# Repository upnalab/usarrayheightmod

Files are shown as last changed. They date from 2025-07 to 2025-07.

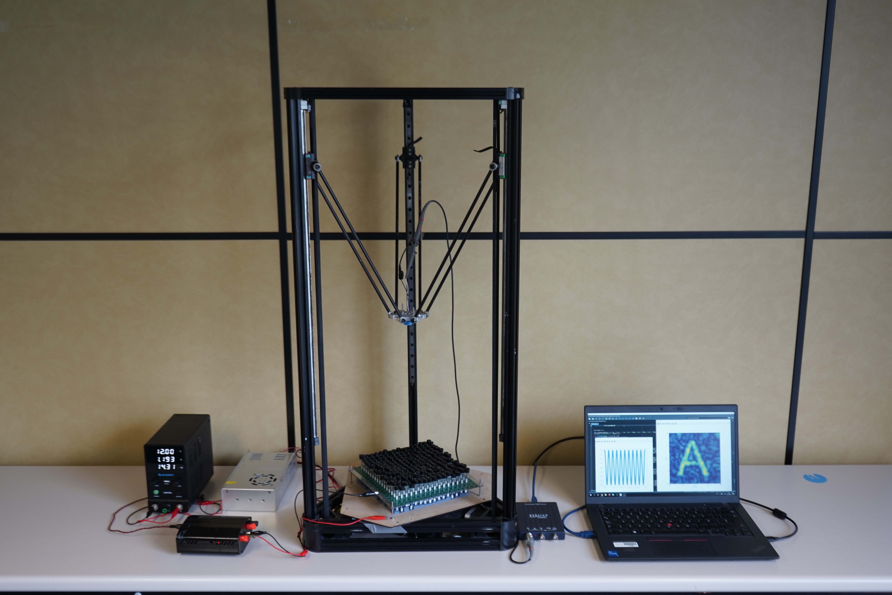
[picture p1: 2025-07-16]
Paper Photos/All Photos/Scan_SetUp/_DSC2688.JPG

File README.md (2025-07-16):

# Generating High-amplitude Acoustic Patterns by Reconfiguring the Height of Emitters Arrays
**Authors:** Mikel Aldea<sup>1</sup>, Soma Mochizuki<sup>2</sup>, Manuel Lopez-Amo<sup>1</sup>, Ivan Fernandez<sup>1</sup>, Tatsuki Fushimi<sup>3</sup> and Asier Marzo<sup>1</sup>.

**Affiliation 1)** Universidad Pública de Navarra, Departamento de Estadística, Informática y Matemáticas, Pamplona, Spain. 

**Affiliation 2)** Graduate School of Comprehensive Human Sciences, University of Tsukuba, Tsukuba, 305-8550 Ibaraki, Japan. 

**Affiliation 3)** Institute of Library, Information and Media Science, University of Tsukuba, Kasuga Campus Kasuga 1-2, Tsukuba 305-8550, Ibaraki, Japan.

Paper published in:

DOI:

Detailed explanation of the files in the git:
```
├── ArrayAmpSliceHeight.py                           -> Main function of the code. Contains a python class to optimize the heights of a grid of transducers while keeping the phase to 0 for all the emitters in the grid. This heights are trained to generate an acoustic pattern at a desired height.
├── Waves.py                                         -> Contains helper functions used throughout the main code. These functions encapsulate common operations such as gneerate a planeGrid, generate normals for the phased array, compute the propagators to calculate the simulated acoustic fields.
├── ImageUtils.py                                    -> Contains functions used to load the images of the desired target pattern to optimize.
├── TestArrayAmpSliceHeight.py                       -> Main executable for ArrayAmpSliceHeight.py. It computes the idea heights for the 3 patterns presented in the paper.
├── TestArrayAmpSliceHeight_ForMNIST10.py            -> Similar to TestArrayAmpSliceHeight.py but used for Figure 4 and 5 of the paper. This code compares the proposed method in the paper against existance method such as Phased optimization. The patterns used to compare are extracted from MNIST10 dataset. 
├── PatternMeasurements.py                           -> Code used to take experimental measurements. It is designed to serally connect to a delta printer (BIQU Kossel9 Plus) and to a PicoScope2004A Series (attached to the tip of the printer). The extruder will be moved in a sqaure grid to take measuremnt of the acoustic field in each step.
├── UtilsMeasurement.py                              -> Contains helper function to both connect to the printer and to the PicoScope.
├── VisualizeMeasurement.py                          -> Code that can be executed to visually check the measurement taken.
├── CreatePlateFromEmitters.py                       -> Generates a mesh to transform into an STL with the heights of the transducers computed by the algorithm proposed in this paper.
├── results                                          -> Result obtained in the paper. ** stands for the specific pattern depicted in each image (i.e., a star shape, the letter A, or the number 12).                         
    ├── Experiment_VS_Simulation_HeightMod_**.png    
    ├── sim_**.png                                   
    ├── meshes                                       -> Mesh generated by CreatePlateFromEmitters.py. This files can be used to generate the metasurfaces used in the paper.
        └── Mesh_heightMod_**.scad                   
    └── STLs                                         -> STLs for the 3D printing the metasurfaces.
        └── STL_heightMod_**.stl
├── measurements                                    -> Directory used to store all the experimental data produced by the paper.
    ├── GenerateImageExpAndSim.py                   -> Code used to generate the images to produce Figure 3 in the article.
    ├── target_**.png
    ├── sim_**.png
    ├── experHeightMod_**.png
    ├── ExperimentalData_HeightMod                  -> Experimental data recorded by the PicoScope each csv in a 128x128 grid of values obtained from the experiments.
        └── HeightMod_**.csv
    └── Simulations                                 -> Simulations used to compare against the experimental data. Each csv has 256 rows where each row provides information about the transducer in the phased array. the file format is: x,y,z,nx,ny,nz,power,frequency,apperture,Type(0=circle,1=square),sx,sy,sz,phase.
        ├── heightMod_**.csv
        └── VisualizeDataFromCsv.py
├── patterns                                        -> This directory contains the images of the patterns used in the paper. This patterns included a star shape, the letter A, the number 12 and 10 random images from MNIST 10 dataset.
│   ├── 12.png
│   ├── A.png
│   ├── star.png
│   ├── mnist10
│   │   ├── Label_0.jpeg
│   │   └── ...
└── results_MNIST10                                -> Stored the results for evaluating and comparing the different optimization methods against the model discussed in the paper.
    └── ...
└── paper photos                                   -> Includes photos taken for the paper and the figures used in the latter.
    └── ...
```

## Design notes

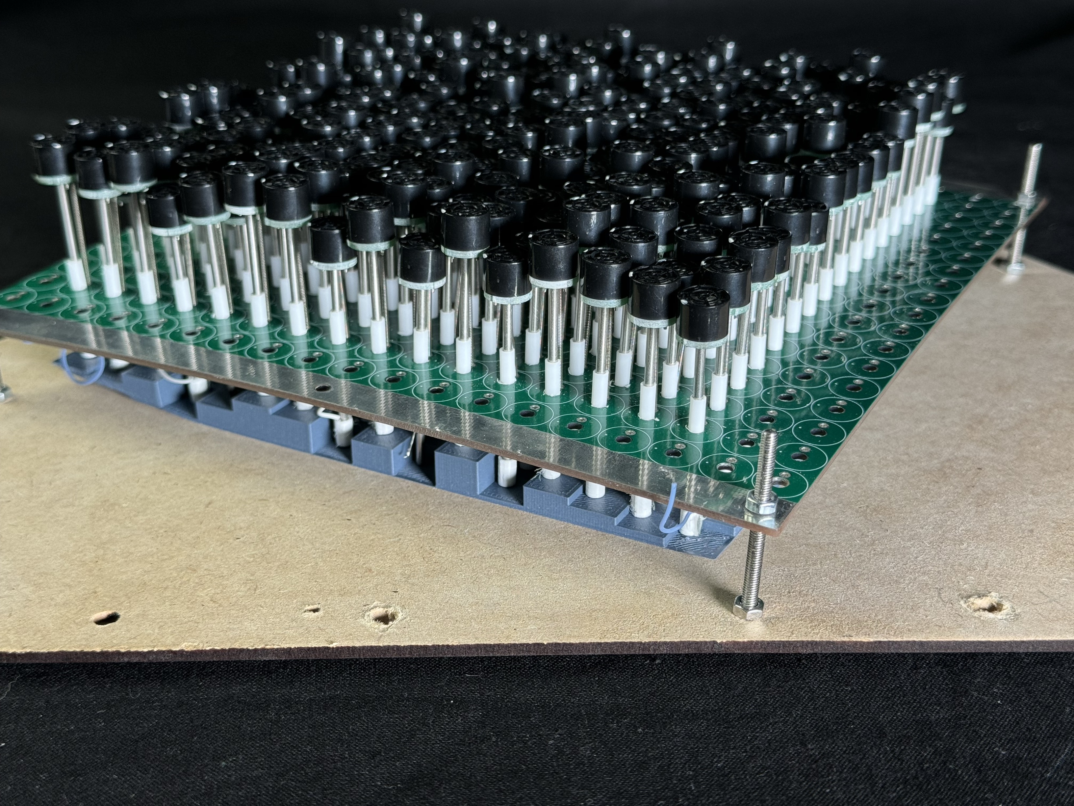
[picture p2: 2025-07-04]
Paper Photos/All Photos/Array/Foto59.png

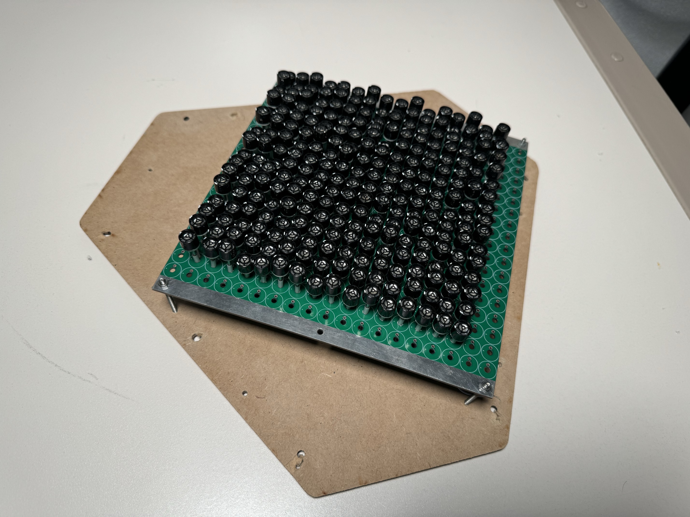
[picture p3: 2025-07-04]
Paper Photos/All Photos/Array/Foto21.png

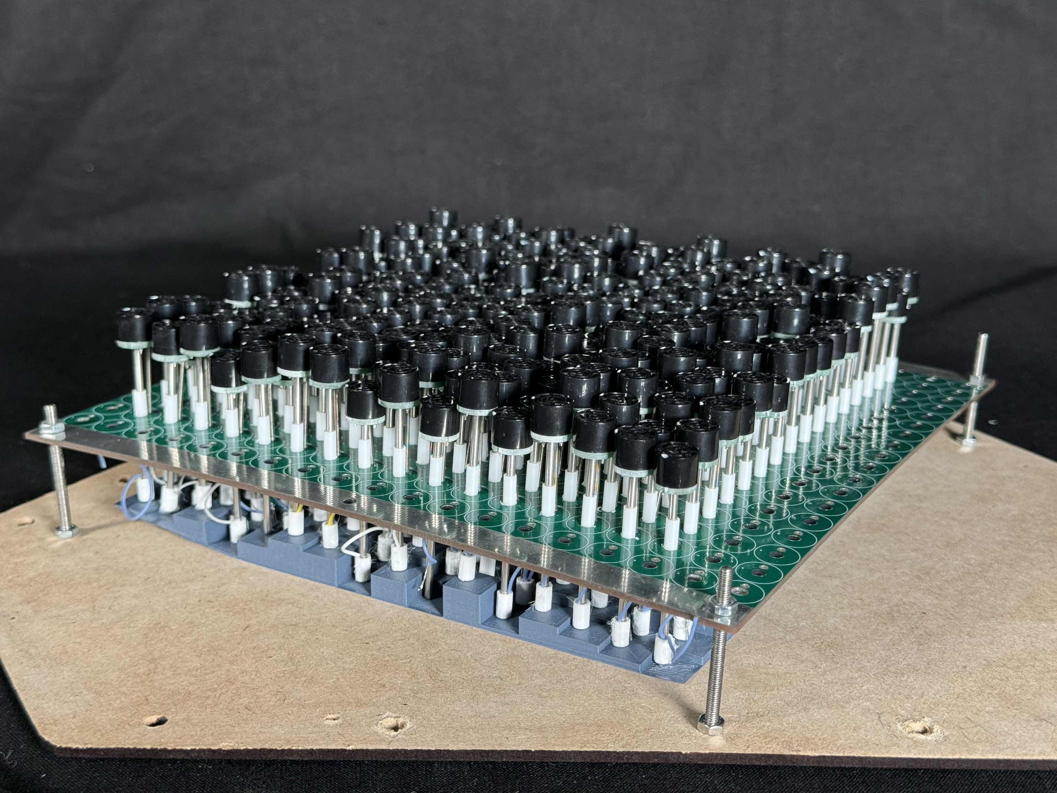
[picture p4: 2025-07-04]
Paper Photos/All Photos/Array/Foto34.png

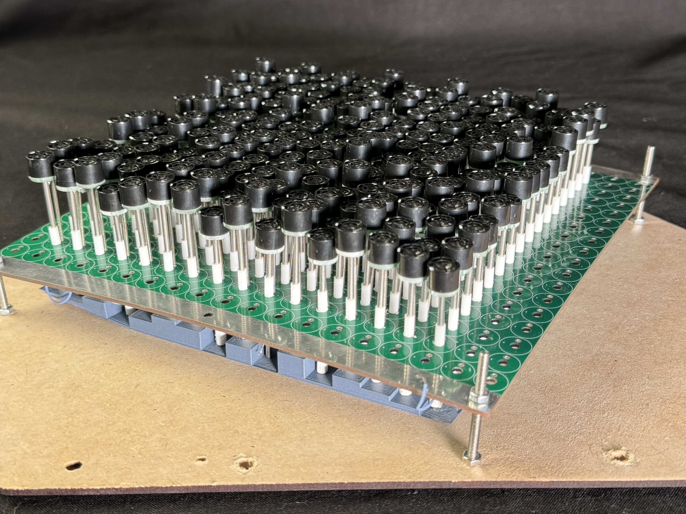
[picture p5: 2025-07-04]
Paper Photos/All Photos/Array/Foto56.png

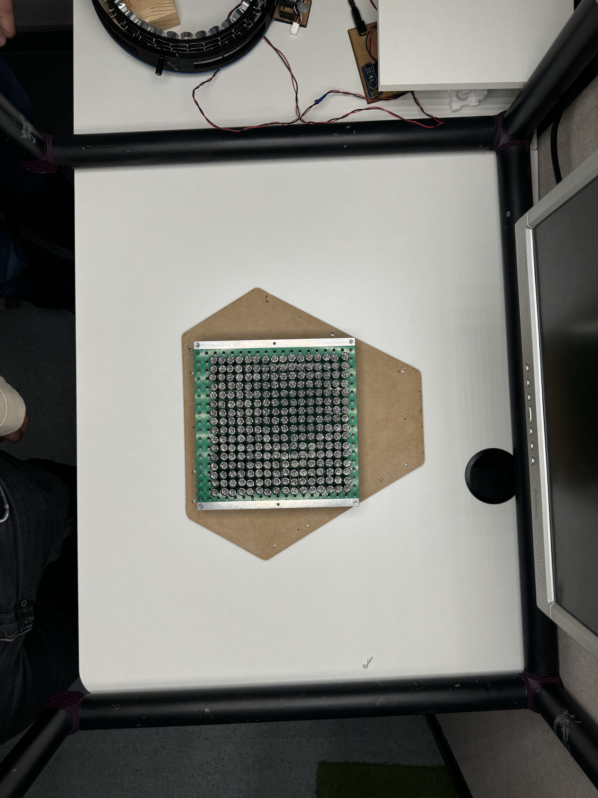
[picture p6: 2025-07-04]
Paper Photos/All Photos/Array/Foto14.png

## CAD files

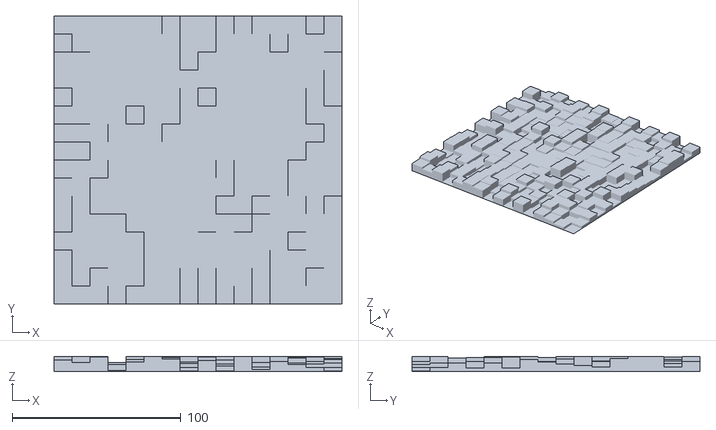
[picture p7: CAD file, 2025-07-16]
results/STLs/STL_heightMod_A.stl
170.7 x 170.7 x 8.70

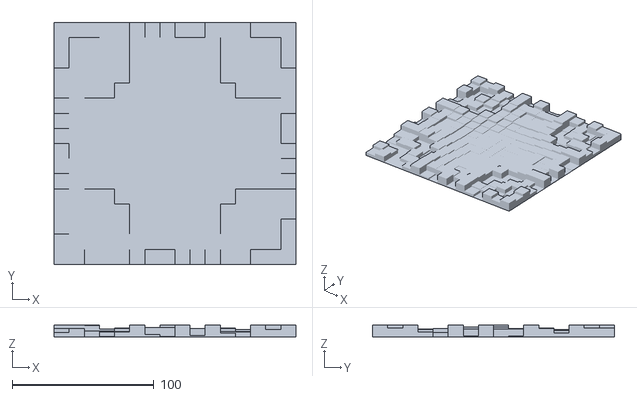
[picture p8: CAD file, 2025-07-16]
results/STLs/STL_heightMod_Star.stl
170.7 x 170.7 x 8.70

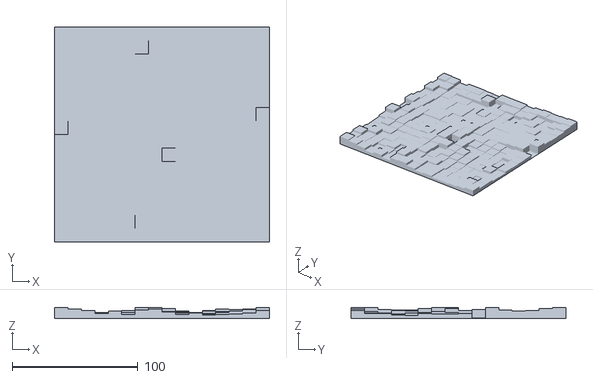
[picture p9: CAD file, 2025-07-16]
results/STLs/STL_heightMod_12.stl
170.7 x 170.7 x 8.70

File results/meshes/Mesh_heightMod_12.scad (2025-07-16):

union() {
	translate(v = [-85.33333333333334, -85.33333333333334, 0]) {
		cube(size = [10.6666666666667, 10.6666666666667, 8.700000461935899]);
	}
	translate(v = [-74.66666666666666, -85.33333333333334, 0]) {
		cube(size = [10.6666666666667, 10.6666666666667, 7.5061604052782]);
	}
	translate(v = [-63.99999999999995, -85.33333333333334, 0]) {
		cube(size = [10.6666666666667, 10.6666666666667, 6.1725968167185]);
	}
	translate(v = [-53.33333333333335, -85.33333333333334, 0]) {
		cube(size = [10.6666666666667, 10.6666666666667, 3.813871987909]);
	}
	translate(v = [-42.66666666666665, -85.33333333333334, 0]) {
		cube(size = [10.6666666666667, 10.6666666666667, 5.8566777639091]);
	}
	translate(v = [-31.99999999999995, -85.33333333333334, 0]) {
		cube(size = [10.6666666666667, 10.6666666666667, 3.2827173031866]);
	}
	translate(v = [-21.33333333333335, -85.33333333333334, 0]) {
		cube(size = [10.6666666666667, 10.6666666666667, 6.8355797462165]);
	}
	translate(v = [-10.66666666666665, -85.33333333333334, 0]) {
		cube(size = [10.6666666666667, 10.6666666666667, 7.645706985890801]);
	}
	translate(v = [-4.973799150320701e-14, -85.33333333333334, 0]) {
		cube(size = [10.6666666666667, 10.6666666666667, 5.1123354256153]);
	}
	translate(v = [10.66666666666665, -85.33333333333334, 0]) {
		cube(size = [10.6666666666667, 10.6666666666667, 3.2912335496394998]);
	}
	translate(v = [21.33333333333325, -85.33333333333334, 0]) {
		cube(size = [10.6666666666667, 10.6666666666667, 4.2894309058785]);
	}
	translate(v = [31.99999999999995, -85.33333333333334, 0]) {
		cube(size = [10.6666666666667, 10.6666666666667, 2.8622421573847]);
	}
	translate(v = [42.66666666666665, -85.33333333333334, 0]) {
		cube(size = [10.6666666666667, 10.6666666666667, 2.9689922135323004]);
	}
	translate(v = [53.33333333333325, -85.33333333333334, 0]) {
		cube(size = [10.6666666666667, 10.6666666666667, 3.4237507402896004]);
	}
	translate(v = [63.99999999999995, -85.33333333333334, 0]) {
		cube(size = [10.6666666666667, 10.6666666666667, 4.533003424108]);
	}
	translate(v = [74.66666666666666, -85.33333333333334, 0]) {
		cube(size = [10.6666666666667, 10.6666666666667, 6.1867124073207]);
	}
	translate(v = [-85.33333333333334, -74.66666666666666, 0]) {
		cube(size = [10.6666666666667, 10.6666666666667, 5.3155630499124]);
	}
	translate(v = [-74.66666666666666, -74.66666666666666, 0]) {
		cube(size = [10.6666666666667, 10.6666666666667, 4.467711192369401]);
	}
	translate(v = [-63.99999999999995, -74.66666666666666, 0]) {
		cube(size = [10.6666666666667, 10.6666666666667, 4.082786724716399]);
	}
	translate(v = [-53.33333333333335, -74.66666666666666, 0]) {
		cube(size = [10.6666666666667, 10.6666666666667, 1.6185141772030998]);
	}
	translate(v = [-42.66666666666665, -74.66666666666666, 0]) {
		cube(size = [10.6666666666667, 10.6666666666667, 3.0523833025246003]);
	}
	translate(v = [-31.99999999999995, -74.66666666666666, 0]) {
		cube(size = [10.6666666666667, 10.6666666666667, 1.8066216630861]);
	}
	translate(v = [-21.33333333333335, -74.66666666666666, 0]) {
		cube(size = [10.6666666666667, 10.6666666666667, 8.700000461935899]);
	}
	translate(v = [-10.66666666666665, -74.66666666666666, 0]) {
		cube(size = [10.6666666666667, 10.6666666666667, 5.2259600393474]);
	}
	translate(v = [-4.973799150320701e-14, -74.66666666666666, 0]) {
		cube(size = [10.6666666666667, 10.6666666666667, 5.390020892769001]);
	}
	translate(v = [10.66666666666665, -74.66666666666666, 0]) {
		cube(size = [10.6666666666667, 10.6666666666667, 3.0766558971256]);
	}
	translate(v = [21.33333333333325, -74.66666666666666, 0]) {
		cube(size = [10.6666666666667, 10.6666666666667, 4.027566280961]);
	}
	translate(v = [31.99999999999995, -74.66666666666666, 0]) {
		cube(size = [10.6666666666667, 10.6666666666667, 2.3891125943511002]);
	}
	translate(v = [42.66666666666665, -74.66666666666666, 0]) {
		cube(size = [10.6666666666667, 10.6666666666667, 1.9034379998221]);
	}
	translate(v = [53.33333333333325, -74.66666666666666, 0]) {
		cube(size = [10.6666666666667, 10.6666666666667, 1.8246892046183]);
	}
	translate(v = [63.99999999999995, -74.66666666666666, 0]) {
		cube(size = [10.6666666666667, 10.6666666666667, 4.4788172140717]);
	}
	translate(v = [74.66666666666666, -74.66666666666666, 0]) {
		cube(size = [10.6666666666667, 10.6666666666667, 3.8776547785848003]);
	}
	translate(v = [-85.33333333333334, -63.99999999999995, 0]) {
		cube(size = [10.6666666666667, 10.6666666666667, 6.897682198137]);
	}
	translate(v = [-74.66666666666666, -63.99999999999995, 0]) {
		cube(size = [10.6666666666667, 10.6666666666667, 3.8400603130459]);
	}
	translate(v = [-63.99999999999995, -63.99999999999995, 0]) {
		cube(size = [10.6666666666667, 10.6666666666667, 3.4093536574393]);
	}
	translate(v = [-53.33333333333335, -63.99999999999995, 0]) {
		cube(size = [10.6666666666667, 10.6666666666667, 2.8971441693603]);
	}
	translate(v = [-42.66666666666665, -63.99999999999995, 0]) {
		cube(size = [10.6666666666667, 10.6666666666667, 4.6724410399794]);
	}
	translate(v = [-31.99999999999995, -63.99999999999995, 0]) {
		cube(size = [10.6666666666667, 10.6666666666667, 2.4921981289982003]);
	}
	translate(v = [-21.33333333333335, -63.99999999999995, 0]) {
		cube(size = [10.6666666666667, 10.6666666666667, 7.2442627184093]);
	}
	translate(v = [-10.66666666666665, -63.99999999999995, 0]) {
		cube(size = [10.6666666666667, 10.6666666666667, 4.4911549098789]);
	}
	translate(v = [-4.973799150320701e-14, -63.99999999999995, 0]) {
		cube(size = [10.6666666666667, 10.6666666666667, 2.8251855306327003]);
	}
	translate(v = [10.66666666666665, -63.99999999999995, 0]) {
		cube(size = [10.6666666666667, 10.6666666666667, 4.5256282806396]);
	}
	translate(v = [21.33333333333325, -63.99999999999995, 0]) {
		cube(size = [10.6666666666667, 10.6666666666667, 2.0661735812202]);
	}
	translate(v = [31.99999999999995, -63.99999999999995, 0]) {
		cube(size = [10.6666666666667, 10.6666666666667, 0.7307201645337]);
	}
	translate(v = [42.66666666666665, -63.99999999999995, 0]) {
		cube(size = [10.6666666666667, 10.6666666666667, 0.5089016827289]);
	}
	translate(v = [53.33333333333325, -63.99999999999995, 0]) {
		cube(size = [10.6666666666667, 10.6666666666667, 1.2173014597967]);
	}
	translate(v = [63.99999999999995, -63.99999999999995, 0]) {
		cube(size = [10.6666666666667, 10.6666666666667, 0.6361953178886]);
	}
	translate(v = [74.66666666666666, -63.99999999999995, 0]) {
		cube(size = [10.6666666666667, 10.6666666666667, 4.0184390868991]);
	}
	translate(v = [-85.33333333333334, -53.33333333333335, 0]) {
		cube(size = [10.6666666666667, 10.6666666666667, 3.388042435795]);
	}
	translate(v = [-74.66666666666666, -53.33333333333335, 0]) {
		cube(size = [10.6666666666667, 10.6666666666667, 6.1399888850748]);
	}
	translate(v = [-63.99999999999995, -53.33333333333335, 0]) {
		cube(size = [10.6666666666667, 10.6666666666667, 2.6903439916670004]);
	}
	translate(v = [-53.33333333333335, -53.33333333333335, 0]) {
		cube(size = [10.6666666666667, 10.6666666666667, 3.6316447563469]);
	}
	translate(v = [-42.66666666666665, -53.33333333333335, 0]) {
		cube(size = [10.6666666666667, 10.6666666666667, 3.4382959034293004]);
	}
	translate(v = [-31.99999999999995, -53.33333333333335, 0]) {
		cube(size = [10.6666666666667, 10.6666666666667, 4.7138685964047]);
	}
	translate(v = [-21.33333333333335, -53.33333333333335, 0]) {
		cube(size = [10.6666666666667, 10.6666666666667, 6.5388622365891]);
	}
	translate(v = [-10.66666666666665, -53.33333333333335, 0]) {
		cube(size = [10.6666666666667, 10.6666666666667, 6.215482824295701]);
	}
	translate(v = [-4.973799150320701e-14, -53.33333333333335, 0]) {
		cube(size = [10.6666666666667, 10.6666666666667, 3.5347285352647004]);
	}
	translate(v = [10.66666666666665, -53.33333333333335, 0]) {
		cube(size = [10.6666666666667, 10.6666666666667, 2.9948897331953]);
	}
	translate(v = [21.33333333333325, -53.33333333333335, 0]) {
		cube(size = [10.6666666666667, 10.6666666666667, 2.1912782590836]);
	}
	translate(v = [31.99999999999995, -53.33333333333335, 0]) {
		cube(size = [10.6666666666667, 10.6666666666667, 1.0774873567745]);
	}
	translate(v = [42.66666666666665, -53.33333333333335, 0]) {
		cube(size = [10.6666666666667, 10.6666666666667, 0.5528551605995]);
	}
	translate(v = [53.33333333333325, -53.33333333333335, 0]) {
		cube(size = [10.6666666666667, 10.6666666666667, 0.3810343528632]);
	}
	translate(v = [63.99999999999995, -53.33333333333335, 0]) {
		cube(size = [10.6666666666667, 10.6666666666667, 1.7551378019154]);
	}
	translate(v = [74.66666666666666, -53.33333333333335, 0]) {
		cube(size = [10.6666666666667, 10.6666666666667, 2.7600516237318002]);
	}
	translate(v = [-85.33333333333334, -42.66666666666665, 0]) {
		cube(size = [10.6666666666667, 10.6666666666667, 2.3933710668236]);
	}
	translate(v = [-74.66666666666666, -42.66666666666665, 0]) {
		cube(size = [10.6666666666667, 10.6666666666667, 3.8259142216295]);
	}
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

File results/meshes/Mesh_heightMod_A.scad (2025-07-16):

union() {
	translate(v = [-85.33333333333334, -85.33333333333334, 0]) {
		cube(size = [10.6666666666667, 10.6666666666667, 6.8611734218895]);
	}
	translate(v = [-74.66666666666666, -85.33333333333334, 0]) {
		cube(size = [10.6666666666667, 10.6666666666667, 5.3775104366242]);
	}
	translate(v = [-63.99999999999995, -85.33333333333334, 0]) {
		cube(size = [10.6666666666667, 10.6666666666667, 8.5248196169734]);
	}
	translate(v = [-53.33333333333335, -85.33333333333334, 0]) {
		cube(size = [10.6666666666667, 10.6666666666667, 0.5869419451802]);
	}
	translate(v = [-42.66666666666665, -85.33333333333334, 0]) {
		cube(size = [10.6666666666667, 10.6666666666667, 5.6032769985497]);
	}
	translate(v = [-31.99999999999995, -85.33333333333334, 0]) {
		cube(size = [10.6666666666667, 10.6666666666667, 8.700000461935899]);
	}
	translate(v = [-21.33333333333335, -85.33333333333334, 0]) {
		cube(size = [10.6666666666667, 10.6666666666667, 7.335332096368]);
	}
	translate(v = [-10.66666666666665, -85.33333333333334, 0]) {
		cube(size = [10.6666666666667, 10.6666666666667, 0.2]);
	}
	translate(v = [-4.973799150320701e-14, -85.33333333333334, 0]) {
		cube(size = [10.6666666666667, 10.6666666666667, 6.3289714649319]);
	}
	translate(v = [10.66666666666665, -85.33333333333334, 0]) {
		cube(size = [10.6666666666667, 10.6666666666667, 0.2]);
	}
	translate(v = [21.33333333333325, -85.33333333333334, 0]) {
		cube(size = [10.6666666666667, 10.6666666666667, 8.700000461935899]);
	}
	translate(v = [31.99999999999995, -85.33333333333334, 0]) {
		cube(size = [10.6666666666667, 10.6666666666667, 1.1058919386006]);
	}
	translate(v = [42.66666666666665, -85.33333333333334, 0]) {
		cube(size = [10.6666666666667, 10.6666666666667, 5.9638753205537]);
	}
	translate(v = [53.33333333333325, -85.33333333333334, 0]) {
		cube(size = [10.6666666666667, 10.6666666666667, 4.1397594518959]);
	}
	translate(v = [63.99999999999995, -85.33333333333334, 0]) {
		cube(size = [10.6666666666667, 10.6666666666667, 2.3638963371515]);
	}
	translate(v = [74.66666666666666, -85.33333333333334, 0]) {
		cube(size = [10.6666666666667, 10.6666666666667, 0.2]);
	}
	translate(v = [-85.33333333333334, -74.66666666666666, 0]) {
		cube(size = [10.6666666666667, 10.6666666666667, 8.700000461935899]);
	}
	translate(v = [-74.66666666666666, -74.66666666666666, 0]) {
		cube(size = [10.6666666666667, 10.6666666666667, 0.2]);
	}
	translate(v = [-63.99999999999995, -74.66666666666666, 0]) {
		cube(size = [10.6666666666667, 10.6666666666667, 6.8748773679137]);
	}
	translate(v = [-53.33333333333335, -74.66666666666666, 0]) {
		cube(size = [10.6666666666667, 10.6666666666667, 4.0963563274592]);
	}
	translate(v = [-42.66666666666665, -74.66666666666666, 0]) {
		cube(size = [10.6666666666667, 10.6666666666667, 1.0360576466657]);
	}
	translate(v = [-31.99999999999995, -74.66666666666666, 0]) {
		cube(size = [10.6666666666667, 10.6666666666667, 8.700000461935899]);
	}
	translate(v = [-21.33333333333335, -74.66666666666666, 0]) {
		cube(size = [10.6666666666667, 10.6666666666667, 8.2589121207594]);
	}
	translate(v = [-10.66666666666665, -74.66666666666666, 0]) {
		cube(size = [10.6666666666667, 10.6666666666667, 2.1387893844395]);
	}
	translate(v = [-4.973799150320701e-14, -74.66666666666666, 0]) {
		cube(size = [10.6666666666667, 10.6666666666667, 8.3900777295231]);
	}
	translate(v = [10.66666666666665, -74.66666666666666, 0]) {
		cube(size = [10.6666666666667, 10.6666666666667, 3.3073880381882]);
	}
	translate(v = [21.33333333333325, -74.66666666666666, 0]) {
		cube(size = [10.6666666666667, 10.6666666666667, 4.848499656468601]);
	}
	translate(v = [31.99999999999995, -74.66666666666666, 0]) {
		cube(size = [10.6666666666667, 10.6666666666667, 0.2]);
	}
	translate(v = [42.66666666666665, -74.66666666666666, 0]) {
		cube(size = [10.6666666666667, 10.6666666666667, 8.700000461935899]);
	}
	translate(v = [53.33333333333325, -74.66666666666666, 0]) {
		cube(size = [10.6666666666667, 10.6666666666667, 4.9511155717074]);
	}
	translate(v = [63.99999999999995, -74.66666666666666, 0]) {
		cube(size = [10.6666666666667, 10.6666666666667, 0.2]);
	}
	translate(v = [74.66666666666666, -74.66666666666666, 0]) {
		cube(size = [10.6666666666667, 10.6666666666667, 2.2898443181067]);
	}
	translate(v = [-85.33333333333334, -63.99999999999995, 0]) {
		cube(size = [10.6666666666667, 10.6666666666667, 6.2427971184253]);
	}
	translate(v = [-74.66666666666666, -63.99999999999995, 0]) {
		cube(size = [10.6666666666667, 10.6666666666667, 1.2287438053636999]);
	}
	translate(v = [-63.99999999999995, -63.99999999999995, 0]) {
		cube(size = [10.6666666666667, 10.6666666666667, 0.2]);
	}
	translate(v = [-53.33333333333335, -63.99999999999995, 0]) {
		cube(size = [10.6666666666667, 10.6666666666667, 4.0609399925917]);
	}
	translate(v = [-42.66666666666665, -63.99999999999995, 0]) {
		cube(size = [10.6666666666667, 10.6666666666667, 0.2]);
	}
	translate(v = [-31.99999999999995, -63.99999999999995, 0]) {
		cube(size = [10.6666666666667, 10.6666666666667, 7.1267898797988]);
	}
	translate(v = [-21.33333333333335, -63.99999999999995, 0]) {
		cube(size = [10.6666666666667, 10.6666666666667, 4.8234913170337]);
	}
	translate(v = [-10.66666666666665, -63.99999999999995, 0]) {
		cube(size = [10.6666666666667, 10.6666666666667, 4.648747262358601]);
	}
	translate(v = [-4.973799150320701e-14, -63.99999999999995, 0]) {
		cube(size = [10.6666666666667, 10.6666666666667, 4.614888564497201]);
	}
	translate(v = [10.66666666666665, -63.99999999999995, 0]) {
		cube(size = [10.6666666666667, 10.6666666666667, 2.3358304657042]);
	}
	translate(v = [21.33333333333325, -63.99999999999995, 0]) {
		cube(size = [10.6666666666667, 10.6666666666667, 5.4242064848542]);
	}
	translate(v = [31.99999999999995, -63.99999999999995, 0]) {
		cube(size = [10.6666666666667, 10.6666666666667, 2.6665787350386]);
	}
	translate(v = [42.66666666666665, -63.99999999999995, 0]) {
		cube(size = [10.6666666666667, 10.6666666666667, 7.5695918545126]);
	}
	translate(v = [53.33333333333325, -63.99999999999995, 0]) {
		cube(size = [10.6666666666667, 10.6666666666667, 7.949530486762501]);
	}
	translate(v = [63.99999999999995, -63.99999999999995, 0]) {
		cube(size = [10.6666666666667, 10.6666666666667, 4.4170705273747]);
	}
	translate(v = [74.66666666666666, -63.99999999999995, 0]) {
		cube(size = [10.6666666666667, 10.6666666666667, 4.9761783935129005]);
	}
	translate(v = [-85.33333333333334, -53.33333333333335, 0]) {
		cube(size = [10.6666666666667, 10.6666666666667, 1.550418664515]);
	}
	translate(v = [-74.66666666666666, -53.33333333333335, 0]) {
		cube(size = [10.6666666666667, 10.6666666666667, 0.2]);
	}
	translate(v = [-63.99999999999995, -53.33333333333335, 0]) {
		cube(size = [10.6666666666667, 10.6666666666667, 3.9791645154356]);
	}
	translate(v = [-53.33333333333335, -53.33333333333335, 0]) {
		cube(size = [10.6666666666667, 10.6666666666667, 1.7415344387292]);
	}
	translate(v = [-42.66666666666665, -53.33333333333335, 0]) {
		cube(size = [10.6666666666667, 10.6666666666667, 0.2]);
	}
	translate(v = [-31.99999999999995, -53.33333333333335, 0]) {
		cube(size = [10.6666666666667, 10.6666666666667, 6.1192799963057]);
	}
	translate(v = [-21.33333333333335, -53.33333333333335, 0]) {
		cube(size = [10.6666666666667, 10.6666666666667, 4.6112834148108]);
	}
	translate(v = [-10.66666666666665, -53.33333333333335, 0]) {
		cube(size = [10.6666666666667, 10.6666666666667, 4.1132074452936]);
	}
	translate(v = [-4.973799150320701e-14, -53.33333333333335, 0]) {
		cube(size = [10.6666666666667, 10.6666666666667, 7.7123985297977]);
	}
	translate(v = [10.66666666666665, -53.33333333333335, 0]) {
		cube(size = [10.6666666666667, 10.6666666666667, 4.328182772547]);
	}
	translate(v = [21.33333333333325, -53.33333333333335, 0]) {
		cube(size = [10.6666666666667, 10.6666666666667, 2.0356193322688]);
	}
	translate(v = [31.99999999999995, -53.33333333333335, 0]) {
		cube(size = [10.6666666666667, 10.6666666666667, 5.2852405838668]);
	}
	translate(v = [42.66666666666665, -53.33333333333335, 0]) {
		cube(size = [10.6666666666667, 10.6666666666667, 8.312379349768099]);
	}
	translate(v = [53.33333333333325, -53.33333333333335, 0]) {
		cube(size = [10.6666666666667, 10.6666666666667, 2.3596830338239005]);
	}
	translate(v = [63.99999999999995, -53.33333333333335, 0]) {
		cube(size = [10.6666666666667, 10.6666666666667, 5.8739267893135]);
	}
	translate(v = [74.66666666666666, -53.33333333333335, 0]) {
		cube(size = [10.6666666666667, 10.6666666666667, 1.8799649456515]);
	}
	translate(v = [-85.33333333333334, -42.66666666666665, 0]) {
		cube(size = [10.6666666666667, 10.6666666666667, 8.363804188370699]);
	}
	translate(v = [-74.66666666666666, -42.66666666666665, 0]) {
		cube(size = [10.6666666666667, 10.6666666666667, 3.6281944390386003]);
	}
	translate(v = [-63.99999999999995, -42.66666666666665, 0]) {
		cube(size = [10.6666666666667, 10.6666666666667, 3.9109905388206]);
	}
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

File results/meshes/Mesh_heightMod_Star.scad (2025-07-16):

union() {
	translate(v = [-85.33333333333334, -85.33333333333334, 0]) {
		cube(size = [10.6666666666667, 10.6666666666667, 3.2420557595789]);
	}
	translate(v = [-74.66666666666666, -85.33333333333334, 0]) {
		cube(size = [10.6666666666667, 10.6666666666667, 6.0149518445134]);
	}
	translate(v = [-63.99999999999995, -85.33333333333334, 0]) {
		cube(size = [10.6666666666667, 10.6666666666667, 0.2]);
	}
	translate(v = [-53.33333333333335, -85.33333333333334, 0]) {
		cube(size = [10.6666666666667, 10.6666666666667, 0.565711224731]);
	}
	translate(v = [-42.66666666666665, -85.33333333333334, 0]) {
		cube(size = [10.6666666666667, 10.6666666666667, 3.6981123171746]);
	}
	translate(v = [-31.99999999999995, -85.33333333333334, 0]) {
		cube(size = [10.6666666666667, 10.6666666666667, 8.700000461935899]);
	}
	translate(v = [-21.33333333333335, -85.33333333333334, 0]) {
		cube(size = [10.6666666666667, 10.6666666666667, 1.8143840039148]);
	}
	translate(v = [-10.66666666666665, -85.33333333333334, 0]) {
		cube(size = [10.6666666666667, 10.6666666666667, 0.3209623151225]);
	}
	translate(v = [-4.973799150320701e-14, -85.33333333333334, 0]) {
		cube(size = [10.6666666666667, 10.6666666666667, 8.700000461935899]);
	}
	translate(v = [10.66666666666665, -85.33333333333334, 0]) {
		cube(size = [10.6666666666667, 10.6666666666667, 1.1756258223205]);
	}
	translate(v = [21.33333333333325, -85.33333333333334, 0]) {
		cube(size = [10.6666666666667, 10.6666666666667, 8.700000461935899]);
	}
	translate(v = [31.99999999999995, -85.33333333333334, 0]) {
		cube(size = [10.6666666666667, 10.6666666666667, 2.8414101012051005]);
	}
	translate(v = [42.66666666666665, -85.33333333333334, 0]) {
		cube(size = [10.6666666666667, 10.6666666666667, 0.2]);
	}
	translate(v = [53.33333333333325, -85.33333333333334, 0]) {
		cube(size = [10.6666666666667, 10.6666666666667, 8.4243662327528]);
	}
	translate(v = [63.99999999999995, -85.33333333333334, 0]) {
		cube(size = [10.6666666666667, 10.6666666666667, 5.3623326726257]);
	}
	translate(v = [74.66666666666666, -85.33333333333334, 0]) {
		cube(size = [10.6666666666667, 10.6666666666667, 8.700000461935899]);
	}
	translate(v = [-85.33333333333334, -74.66666666666666, 0]) {
		cube(size = [10.6666666666667, 10.6666666666667, 6.1117646887898]);
	}
	translate(v = [-74.66666666666666, -74.66666666666666, 0]) {
		cube(size = [10.6666666666667, 10.6666666666667, 4.230508454889001]);
	}
	translate(v = [-63.99999999999995, -74.66666666666666, 0]) {
		cube(size = [10.6666666666667, 10.6666666666667, 0.2]);
	}
	translate(v = [-53.33333333333335, -74.66666666666666, 0]) {
		cube(size = [10.6666666666667, 10.6666666666667, 3.7915621556341]);
	}
	translate(v = [-42.66666666666665, -74.66666666666666, 0]) {
		cube(size = [10.6666666666667, 10.6666666666667, 4.0355982396751]);
	}
	translate(v = [-31.99999999999995, -74.66666666666666, 0]) {
		cube(size = [10.6666666666667, 10.6666666666667, 8.700000461935899]);
	}
	translate(v = [-21.33333333333335, -74.66666666666666, 0]) {
		cube(size = [10.6666666666667, 10.6666666666667, 6.9393383942544]);
	}
	translate(v = [-10.66666666666665, -74.66666666666666, 0]) {
		cube(size = [10.6666666666667, 10.6666666666667, 6.7203933045268]);
	}
	translate(v = [-4.973799150320701e-14, -74.66666666666666, 0]) {
		cube(size = [10.6666666666667, 10.6666666666667, 6.918397606164199]);
	}
	translate(v = [10.66666666666665, -74.66666666666666, 0]) {
		cube(size = [10.6666666666667, 10.6666666666667, 6.0253672905266]);
	}
	translate(v = [21.33333333333325, -74.66666666666666, 0]) {
		cube(size = [10.6666666666667, 10.6666666666667, 8.700000461935899]);
	}
	translate(v = [31.99999999999995, -74.66666666666666, 0]) {
		cube(size = [10.6666666666667, 10.6666666666667, 4.0358340971171005]);
	}
	translate(v = [42.66666666666665, -74.66666666666666, 0]) {
		cube(size = [10.6666666666667, 10.6666666666667, 3.6328347537666]);
	}
	translate(v = [53.33333333333325, -74.66666666666666, 0]) {
		cube(size = [10.6666666666667, 10.6666666666667, 1.1928212966768998]);
	}
	translate(v = [63.99999999999995, -74.66666666666666, 0]) {
		cube(size = [10.6666666666667, 10.6666666666667, 0.2]);
	}
	translate(v = [74.66666666666666, -74.66666666666666, 0]) {
		cube(size = [10.6666666666667, 10.6666666666667, 6.2917902737855]);
	}
	translate(v = [-85.33333333333334, -63.99999999999995, 0]) {
		cube(size = [10.6666666666667, 10.6666666666667, 0.2]);
	}
	translate(v = [-74.66666666666666, -63.99999999999995, 0]) {
		cube(size = [10.6666666666667, 10.6666666666667, 0.2]);
	}
	translate(v = [-63.99999999999995, -63.99999999999995, 0]) {
		cube(size = [10.6666666666667, 10.6666666666667, 0.2]);
	}
	translate(v = [-53.33333333333335, -63.99999999999995, 0]) {
		cube(size = [10.6666666666667, 10.6666666666667, 4.5062083423137]);
	}
	translate(v = [-42.66666666666665, -63.99999999999995, 0]) {
		cube(size = [10.6666666666667, 10.6666666666667, 0.2]);
	}
	translate(v = [-31.99999999999995, -63.99999999999995, 0]) {
		cube(size = [10.6666666666667, 10.6666666666667, 8.142586205899699]);
	}
	translate(v = [-21.33333333333335, -63.99999999999995, 0]) {
		cube(size = [10.6666666666667, 10.6666666666667, 5.6949787445366]);
	}
	translate(v = [-10.66666666666665, -63.99999999999995, 0]) {
		cube(size = [10.6666666666667, 10.6666666666667, 4.4186975479125]);
	}
	translate(v = [-4.973799150320701e-14, -63.99999999999995, 0]) {
		cube(size = [10.6666666666667, 10.6666666666667, 4.0060462102293]);
	}
	translate(v = [10.66666666666665, -63.99999999999995, 0]) {
		cube(size = [10.6666666666667, 10.6666666666667, 5.7704982951283]);
	}
	translate(v = [21.33333333333325, -63.99999999999995, 0]) {
		cube(size = [10.6666666666667, 10.6666666666667, 7.8088183559477]);
	}
	translate(v = [31.99999999999995, -63.99999999999995, 0]) {
		cube(size = [10.6666666666667, 10.6666666666667, 0.2]);
	}
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

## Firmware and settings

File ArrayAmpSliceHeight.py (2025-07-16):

import tensorflow as tf
import numpy as np

class ArrayAmpSlice:
    def __init__(self):
        self.iters = 400
        self.showLossEvery = 20
        self.learningRate = 0.001
        
        self.c = 340
        self.fr = 40000
        self.wavelength = self.c / self.fr 
        
        
    def optimizeAmpSlice(self, target, distTarget, outputPositions, coordsXY, nEmitters, optimizeHeight = True, optimizePhase = False, optimizeAmp = False):        
        targetFlat = tf.constant( tf.reshape(target, [-1]) ) # To be flatten
        
        outputPositionsP = outputPositions[np.newaxis, :, :]
        coordsXY = coordsXY[:, np.newaxis, :]
        
        normals = [0,0,1]
        diffXY = outputPositionsP[:,:,:2] - coordsXY  

        #initial heights = 0
        if optimizeHeight:
            heights = tf.Variable( tf.zeros([nEmitters,1], dtype="float32"), trainable=True, 
                                  constraint= lambda h : tf.clip_by_value(h, clip_value_min = 0.0, clip_value_max = self.wavelength) ) # Min and Max value are totally arbitrary
        else:
            heights = tf.Variable( tf.zeros([nEmitters,1], dtype="float32"), trainable=False)
        
        if optimizePhase:
            phases = tf.Variable( tf.random.uniform([1,nEmitters], minval = -np.pi, maxval = np.pi, dtype="float32"), trainable=True,
                                  constraint= lambda h : tf.clip_by_value(h, clip_value_min = -np.pi, clip_value_max = np.pi) )
        
        else:
            phases = tf.Variable( tf.zeros([1,nEmitters], dtype="float32"), trainable=False )
            
        if optimizeAmp:
                cosAmps = tf.Variable( tf.random.uniform([1,nEmitters], minval=-np.pi, maxval=np.pi, dtype="float32"), trainable=True,
                                      constraint= lambda h : tf.clip_by_value(h, clip_value_min = -np.pi/2, clip_value_max = np.pi/2) )
        
        else:  
            cosAmps = tf.Variable( tf.zeros([1,nEmitters], dtype="float32"), trainable=False  )
        
        if not optimizeHeight:
            shapeA = diffXY.shape
            shapeB = outputPositionsP.shape
            propagators = np.zeros((shapeA[0], shapeB[0]), dtype=complex)
            diffZ = outputPositionsP[:,:,2] - heights
            
            nd = tf.sqrt(diffXY[:, :, 0]**2 + diffXY[:, :, 1]**2 + diffZ**2) 
            nn = np.linalg.norm(normals, axis=0)
    
            angle = np.arccos(
                (diffXY[:, :, 0] * normals[0]
                + diffXY[:, :,  1] * normals[1]
                + diffZ * normals[2]) / nd / (nn + 1e-07) # + 1e-07 to avoid division by zero
            )
            
            emitterApperture = 0.009
            c = 340
            fr = 40000
            wavelength = c / fr 
            k = 2 * np.pi / wavelength


            dum = 0.5 * emitterApperture * k * np.sin(angle)
            dire = np.sinc(dum / np.pi)
            propagators = tf.complex(dire / nd, 0.) * tf.complex(tf.cos(k * nd), tf.sin(k * nd))        
            propagatorsConst = tf.constant( propagators, dtype="complex64" ) # Transform into a tf.constant to speed the training
        else:
            propagatorsConst = None

        
        optim_height    = tf.keras.optimizers.Adam(learning_rate=self.learningRate)
        optim_phase     = tf.keras.optimizers.Adam(learning_rate=0.1)
        optim_amp       = tf.keras.optimizers.Adam(learning_rate=0.1)
            
        best_loss = 1
        best_heights = None
        best_phases = None
        best_amps = None
        for i in range(self.iters):
            with tf.GradientTape() as tape:
                loss = ArrayAmpSlice.targetFunction(heights, distTarget, outputPositionsP, diffXY, normals, targetFlat, phases, cosAmps, propagatorsConst, optimizeHeight)
                
                if loss < best_loss:
                    best_loss    = tf.convert_to_tensor(loss.numpy(),    dtype = tf.float32)
                    best_heights = tf.convert_to_tensor(heights.numpy(), dtype = tf.float32)
                    best_phases  = tf.convert_to_tensor(phases.numpy(),  dtype = tf.float32)
                    best_amps    = tf.convert_to_tensor(cosAmps.numpy(), dtype = tf.float32)
                
                    
                if optimizeHeight and not optimizePhase and not optimizeAmp:
                    grads = tape.gradient(loss, [heights])
                    optim_height.apply_gradients(zip(grads, [heights]))
                
                if not optimizeHeight and optimizePhase and not optimizeAmp:
                    grads = tape.gradient(loss, [phases])
                    optim_phase.apply_gradients(zip(grads, [phases]))
                
                if optimizeHeight and not optimizePhase and optimizeAmp:
                    grads = tape.gradient(loss, [heights, cosAmps])
                    optim_height.apply_gradients([(grads[0], heights)])
                    optim_amp.apply_gradients([(grads[1], cosAmps)])
                    
                if not optimizeHeight and optimizePhase and optimizeAmp:
                    grads = tape.gradient(loss, [phases, cosAmps])                    
                    optim_phase.apply_gradients([(grads[0], phases)])
                    optim_amp.apply_gradients([(grads[1], cosAmps)])
                    
                if optimizeHeight and optimizePhase and not optimizeAmp:
                    grads = tape.gradient(loss, [heights, phases])
                    optim_height.apply_gradients([(grads[0], heights)])
                    optim_phase.apply_gradients([(grads[1], phases)])
                
                if optimizeHeight and optimizePhase and optimizeAmp:
                    grads = tape.gradient(loss, [heights, phases, cosAmps])
                    optim_height.apply_gradients([(grads[0], heights)])
                    optim_phase.apply_gradients([(grads[1], phases)])
                    optim_amp.apply_gradients([(grads[2], cosAmps)])
            
            if i % self.showLossEvery == 0 and i != 0:
                print(f'Iteration {i} of {self.iters} Loss = {loss}')
                
                
        ampField = ArrayAmpSlice.outputField(best_heights, distTarget, outputPositionsP, diffXY, normals, best_phases, best_amps, propagatorsConst, optimizeHeight)
        ampField = tf.reshape( ampField, [target.shape[0], target.shape[1]])
        
        emitterPositions = np.concatenate((coordsXY[:,0,:], np.array([heights[:,0]]).T), axis=1)
        return best_loss, best_heights, best_phases, emitterPositions, ampField, tf.cos( best_amps )
    
    def outputField(heights, distTarget, outputPositionsP, diffXY, normals, phases, cosAmps, propagatorsConst, heightMod):
        if heightMod:
            shapeA = diffXY.shape
            shapeB = outputPositionsP.shape
            propagators = np.zeros((shapeA[0], shapeB[0]), dtype=complex)
            
            diffZ = outputPositionsP[:,:,2] - heights
            
            nd = tf.sqrt(diffXY[:, :, 0]**2 + diffXY[:, :, 1]**2 + diffZ**2) 
            nn = np.linalg.norm(normals, axis=0)
    
            angle = np.arccos(
                (diffXY[:, :, 0] * normals[0]
                + diffXY[:, :,  1] * normals[1]
                + diffZ * normals[2]) / nd / (nn + 1e-07) # + 1e-07 to avoid division by zero
            )
            
            emitterApperture = 0.009
            c = 340
            fr = 40000
            wavelength = c / fr 
            k = 2 * np.pi / wavelength

            dum = 0.5 * emitterApperture * k * np.sin(angle)
            dire = np.sinc(dum / np.pi)
            propagators = tf.complex(dire / nd, 0.) * tf.complex(tf.cos(k * nd), tf.sin(k * nd)) 
            propagatorsConst = tf.constant( propagators, dtype="complex64" ) # Transform into a tf.constant to speed the training
            
        # All emitters Amplitude 1 and phase = phases
        amps = tf.cos( cosAmps )
        emitters =  tf.complex(amps * tf.cos(phases), amps * tf.sin(phases) )
        
        field = emitters @ propagatorsConst
        
        ampField = tf.abs( tf.reshape(field, [-1]) ) # -1 To be flatten
        return ampField
            
    def targetFunction(heights, distTarget, outputPositionsP, diffXY, normal, targetFlat, phases, cosAmps, propagatorsConst, heightMod):
        ampField = ArrayAmpSlice.outputField(heights, distTarget, outputPositionsP, diffXY, normal, phases, cosAmps, propagatorsConst, heightMod)
        
        maxAmp = tf.reduce_max( ampField )
        ampField = ampField / maxAmp
        loss = tf.reduce_mean(tf.square(ampField - targetFlat)) #mse
        
        return loss

if __name__ == '__main__':
    import matplotlib.pyplot as plt
    from ImageUtils import ImageUtils
    from Waves import Waves
    
    arraySize = 0.16
    targetSize = 0.16
    emittersPerSide = 16
    nEmitters = emittersPerSide * emittersPerSide
    emitterApperture = 0.009
    slicePx = 128
    distTarget = 0.16
    c = 340
    fr = 40000
    wavelength = c / fr 
    k = 2 * np.pi / wavelength
    
    #targets
    cPath = "patterns/"
    path = "A" # Example pattern
    target = ImageUtils.loadNorm(cPath + path + ".png", slicePx)
    
    lX = np.linspace(0 - arraySize / 2, 0 + arraySize / 2, emittersPerSide)
    lY = np.linspace(0 - arraySize / 2, 0 + arraySize / 2, emittersPerSide)
    coordsXY = np.meshgrid(lX, lY)
    coordsXY = np.vstack([np.ravel(coord) for coord in coordsXY]).T
    
    outputPositions = Waves.planeGridZ(0,0, distTarget, targetSize, targetSize, slicePx, slicePx)
    
    
    opti = ArrayAmpSlice()
    opti.iters = 1500
    opti.showLossEvery = 100 #opti.iters + 1
    loss, heights, phases, emitterPositions, ampField, amps = opti.optimizeAmpSlice(target, distTarget, outputPositions, coordsXY, nEmitters)
    
    # Plot the example
    plt.figure()
    plt.imshow(ampField, cmap = plt.cm.gist_heat, extent=[outputPositions[:,0].min(),outputPositions[:,0].max(),outputPositions[:,1].min(),outputPositions[:,1].max()])
    plt.colorbar(label = "Normalized Amplitude")
    plt.xlabel('x(mm)')
    plt.ylabel('y(mm)')
    plt.show()
    
    # Plot the example in 3D
    ax = plt.figure().add_subplot(projection='3d')
    cs2 = ax.scatter(emitterPositions[:,0], emitterPositions[:,1], emitterPositions[:,2], c = phases, alpha = np.round(amps,5), cmap = plt.cm.hsv, vmin = -np.pi, vmax = np.pi)
    cs  = ax.scatter(outputPositions[:,0],  outputPositions[:,1],  outputPositions[:,2], c = ampField, cmap = plt.cm.gist_heat)
    cbar = plt.colorbar(cs2, ax = ax, label='Phase (rad)')
    ticks = [-np.pi, -np.pi/2, 0, np.pi/2, np.pi]
    tick_labels = [r"$-\pi$", r"$-\frac{\pi}{2}$", "0", r"$\frac{\pi}{2}$", r"$\pi$"]

    cbar.set_ticks(ticks)
    cbar.set_ticklabels(tick_labels)
    
    ax.set_zticks(np.arange(0, distTarget+1e-2, 2e-2))
    ax.set_xticks(np.arange(outputPositions[:,0].min(),outputPositions[:,0].max()+1e-2, 2e-2))
    ax.set_yticks(np.arange(outputPositions[:,1].min(),outputPositions[:,1].max()+1e-2, 2e-2))
    plt.show()
        
        

    
    


    

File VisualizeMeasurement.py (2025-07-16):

import pandas as pd
import os
import matplotlib.pyplot as plt
import ctypes
import numpy as np
from Waves import Waves

import matplotlib.lines as lines

plt.close('all')
emitterApperture = 0.009
c = 340
fr = 40000
wavelength = c / fr 
k = 2 * np.pi / wavelength


def plotFlipper(df,simCounterpart,wavelength):
    #We take the Experimental measurements' results
    df_Pa = df/df.max().max()
    np_Pa=df_Pa.to_numpy()
    np_Pa_Inv=np.flip(np_Pa, 0)
    
    
    #We take the simulation results   
    emPositions=np.array((simCounterpart.iloc[:,0],simCounterpart.iloc[:,1],simCounterpart.iloc[:,2])).T
    sizeXY=0.175
    resolution=64

    outputPositions = Waves.planeGridZ(0,0, 0.16, sizeXY, sizeXY, resolution, resolution)
    normals = Waves.constNormals(emPositions, [0,0,1])
    propagators = Waves.calcPropagatorsPistonsToPoints(emPositions, normals, outputPositions, k, emitterApperture)
    propagatorsConst =  propagators # Transform into a tf.constant to speed the training
    phasesColumn=np.array(simCounterpart.iloc[:,-1]).reshape(-1)
    emitters =   np.cos(phasesColumn)+ np.sin(phasesColumn) *1.0j
    field = emitters @ propagatorsConst
    ampField = np.abs( np.reshape(field, [64,64]) ) # -1 To be flatten
    ampFieldInv=np.flip(ampField, 0)
    
    #wavelenght calc for the subplot
    RealLifeSizePixel=sizeXY/resolution #sizeXY is the lenght of the simulated pattern, m
    realPixelsWavelength=wavelength/RealLifeSizePixel #wavelenght related to the image m/m 
    subplotLenght=5 #it is in inches, 1 inch= 2.54cm
    dpi=100
    figInchessWaveLenght=(subplotLenght/resolution)*realPixelsWavelength
    
    fig,ax= plt.subplots(ncols=2,figsize=(subplotLenght*2, subplotLenght),dpi=dpi)
    
    line_length_fig = figInchessWaveLenght / fig.get_size_inches()[0]  # Normalized width (0-1 range)    
    # Draw a line in figure coordinates
    x_start = 0.4  # Start position (normalized, 10% from the left edge)
    y_position = 0.2  # Position (normalized, 90% from the bottom)
    x_end = x_start + line_length_fig  # End position based on the desired length
    
    # Add the line using Line2D in figure coordinates
    line = lines.Line2D([x_start, x_end], [y_position, y_position], transform=fig.transFigure, color='red', lw=2)
    fig.add_artist(line)
    fig.text(x_start, y_position + 0.02, f'  λ', color='white')
    fig.suptitle(name)
    im=ax[0].imshow(np_Pa, origin = 'lower', cmap = plt.cm.gist_heat)
    ax[0].set_title('Simulation')
    ax[1].imshow(ampFieldInv, origin = 'lower', cmap = plt.cm.gist_heat)
    ax[1].set_title('Experiment')
    fig.subplots_adjust(right=0.8)
    cbar_ax = fig.add_axes([0.85, 0.15, 0.03, 0.7])
    fig.colorbar(im, cax=cbar_ax)
    
    plt.savefig(f'results/Experiment_VS_Simulation_{name.split(".")[0]}.png', dpi = 1200)
    plt.show()
    
print(f'----HeightMod-----------')
for name in os.listdir('measurements/ExperimentalData_HeightMod'):
    print(name)
    
    if '.csv' in name:
        df = pd.read_csv(f'measurements/ExperimentalData_HeightMod/{name}', header = None)
        try:
            simCounterpart= pd.read_csv(f'measurements/Simulations/{name}', header = None)
            plotFlipper(df,simCounterpart,wavelength)
            
        except Exception as error:
            print(f'error: {error}')

          

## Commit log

2025-07-04 Intial commit
    Initial commit with the experimental data, paper photos and patterns. Code remains to be cleaned
    [HeightMod_12.csv, HeightMod_A.csv, HeightMod_Star.csv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]
2025-07-04 Code - (Unclean)
    [Transductor_10mm.stl]
2025-07-16 Updated Code
    [Label_0.csv, Label_1.csv, Label_2.csv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]
2025-07-16 Update V2
    [Mesh_heightMod_12.scad, Mesh_heightMod_A.scad, Mesh_heightMod_Star.scad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]
